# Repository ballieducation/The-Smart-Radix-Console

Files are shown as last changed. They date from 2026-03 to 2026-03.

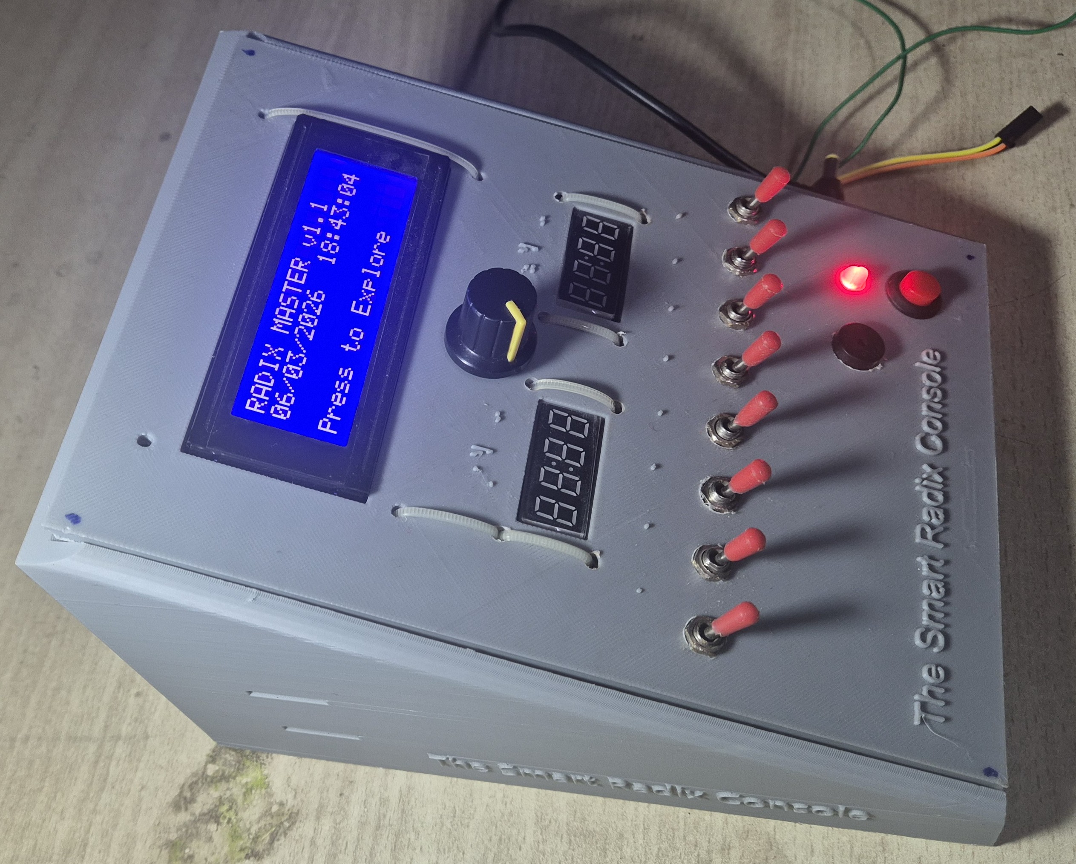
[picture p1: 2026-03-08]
Cover_Image.jpg

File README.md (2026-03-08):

Radix Master v1.1 — Open Source STM32 STEM Learning Console | 12 Games | Binary · DNA · Chemistry
Hands-on educational hardware console teaching Digital Logic, Molecular Biology and Chemistry through interactive switch-based gameplay

## Project Overview

Radix Master v1.1 is a self-contained, hardware-based educational system powered by the STM32 Blue Pill microcontroller. It is designed to bridge the gap between abstract academic theory and genuine conceptual understanding by converting curriculum topics into 
timed, tactile problem-solving challenges.
Students interact with an 8-bit DIP switch array, a rotary encoder, a 20×4 LCD, and dual 7-segment displays — moving learning away from passive screen interaction toward deliberate, physical engagement. The system is fully open-source and customizable for classroom deployment.

━━━━━━━━━━━━━━━━━
## Educational Objectives
━━━━━━━━━━━━━━━━━

This console directly supports learning outcomes in:

COMPUTER SCIENCE
- Binary and hexadecimal number representation
- Bitwise operations: AND, OR, XOR, NAND, NOR, XNOR, NOT
- Base conversion across decimal, binary, and hexadecimal
- Binary arithmetic: addition, subtraction, 
  multiplication, division

MATHEMATICS
- Prime number theory and identification
- Pattern recognition under time pressure

COMMUNICATION TECHNOLOGY  
- Morse code signal encoding and timing

CHEMISTRY & PHYSICS
- Electron shell configuration
- Valence electron identification across 118 elements
- Periodic table navigation

MOLECULAR BIOLOGY
- RNA codon translation using Base-4 encoding
- Gene regulation via bitmask logic
- ABO blood group antigen compatibility

━━━━━━━━━━━━━━━━━
## Hardware Components
━━━━━━━━━━━━━━━━━

Component              | Role
-----------------------|---------------------------
STM32F103C8T6          | Main microcontroller
20×4 I2C LCD (0x27)    | Game display
8-Position DIP Switch  | Student input interface
TM1637 (×2)            | Score + countdown timer
Rotary Encoder         | Menu navigation
Active Buzzer          | Audio feedback
STM32 RTC              | Real-time clock on dashboard

━━━━━━━━━━━━━━━━━
## Pin Mapping
━━━━━━━━━━━━━━━━━

Switch S0–S7    → PA0–PA7   (Digital Input, Pull-up)
Encoder CLK     → PB13      (Interrupt)
Encoder DT      → PB12      (Input)
Encoder SW      → PB14      (Input, Pull-up)
Score TM1637    → PB10/PB11 (CLK/DIO)
Timer TM1637    → PB0/PB1   (CLK/DIO)
I2C LCD         → PB6/PB7   (SCL/SDA)
Buzzer          → PA15      (Digital Output)

━━━━━━━━━━━━━━━━━
## System Architecture
━━━━━━━━━━━━━━━━━

The firmware uses a UIState enum to manage 5 system 
states cleanly:

  STATE_DASHBOARD    — Live RTC clock display
  STATE_MENU         — Scrollable game selector
  STATE_GAME_RUNNING — Active game dispatcher
  STATE_RTC_SETUP    — Field-editable clock setup
  STATE_SELF_TEST    — Hardware diagnostic mode

Each game is assigned a unique activeGame ID and dispatched through a central loop() switch, keeping game logic fully modular and independently expandable.

━━━━━━━━━━━━━━━━━
## The "Ready Gate" Mechanic
━━━━━━━━━━━━━━━━━

Before timed games begin, the system requires the student to reset all 8 switches to the OFF (0) position. 
This physical zeroing serves two purposes:

1. Ensures a fair, clean starting state for every round
2. Acts as a deliberate mental reset — priming the 
   student before the timer begins

━━━━━━━━━━━━━━━━━
## Libraries Required
━━━━━━━━━━━━━━━━━

- Wire.h
- LiquidCrystal_I2C.h
- STM32RTC.h
- TM1637Display.h

━━━━━━━━━━━━━━━━━
## Classroom Deployment Notes
━━━━━━━━━━━━━━━━━

- All string literals use the F() macro to preserve RAM for game variables
- Games are fully independent — teachers can disable specific modules by commenting out menu entries
- Self Test mode allows hardware verification before class sessions
- RTC Setup mode enables accurate date/time stamping without a PC connection

> A hardware-based educational console that teaches Binary Logic, 
> Molecular Biology, Chemistry and Mathematics through 
> real-time, tactile switch-based gameplay.

---

## 📚 Subjects Covered
- 💻 Computer Science — Binary, Hex, Bitwise Logic
- 🧮 Mathematics — Prime Numbers, Binary Arithmetic  
- 📡 Communication — Morse Code
- ⚗️ Chemistry — Electron Shells, Periodic Table
- 🧬 Biology — Codon Translation, Gene Expression, Blood Match

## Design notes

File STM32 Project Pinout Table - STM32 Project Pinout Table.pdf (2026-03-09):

Connection Table (The Smart Radix Console)
S.NO | Component | Component Pin | STM32 Pin | Notes
1 | SPDT Toggle Switch S0 | COM Pin | PA0 | Digital Input Pull-up
2 | SPDT Toggle Switch S1 | COM Pin | PA1 | Digital Input Pull-up
3 | SPDT Toggle Switch S2 | COM Pin | PA2 | Digital Input Pull-up
4 | SPDT Toggle Switch S3 | COM Pin | PA3 | Digital Input Pull-up
5 | SPDT Toggle Switch S4 | COM Pin | PA4 | Digital Input Pull-up
6 | SPDT Toggle Switch S5 | COM Pin | PA5 | Digital Input Pull-up
7 | SPDT Toggle Switch S6 | COM Pin | PA6 | Digital Input Pull-up
8 | SPDT Toggle Switch S7 | COM Pin | PA7 | Digital Input Pull-up
9 | SPDT Toggle Switch S0 | NC Pin | GND | Normally Close to GND
10 | SPDT Toggle Switch S1 | NC Pin | GND | Normally Close to GND
11 | SPDT Toggle Switch S2 | NC Pin | GND | Normally Close to GND
12 | SPDT Toggle Switch S3 | NC Pin | GND | Normally Close to GND
13 | SPDT Toggle Switch S4 | NC Pin | GND | Normally Close to GND
14 | SPDT Toggle Switch S5 | NC Pin | GND | Normally Close to GND
15 | SPDT Toggle Switch S6 | NC Pin | GND | Normally Close to GND
16 | SPDT Toggle Switch S7 | NC Pin | GND | Normally Close to GND
17 | SPDT Toggle Switch S0 | NO Pin | 5V | Normally Open to VCC
18 | SPDT Toggle Switch S1 | NO Pin | 5V | Normally Open to VCC
19 | SPDT Toggle Switch S2 | NO Pin | 5V | Normally Open to VCC
20 | SPDT Toggle Switch S3 | NO Pin | 5V | Normally Open to VCC
21 | SPDT Toggle Switch S4 | NO Pin | 5V | Normally Open to VCC
22 | SPDT Toggle Switch S5 | NO Pin | 5V | Normally Open to VCC
23 | SPDT Toggle Switch S6 | NO Pin | 5V | Normally Open to VCC
24 | SPDT Toggle Switch S7 | NO Pin | 5V | Normally Open to VCC
25 | Rotary Encoder EC11 | CLK (A) | PB13 | Interrupt Input
26 | Rotary Encoder EC11 | DT (B) | PB12 | Digital Input
27 | Rotary Encoder EC11 | SW (Button) | PB14 | Digital Input Pull-up
28 | Rotary Encoder EC11 | GND (-) | GND | Common Ground
29 | Rotary Encoder EC11 | GND (-) | GND | Common Ground
30 | TM1637 Score Display | CLK | PB10 | Serial Clock
31 | TM1637 Score Display | DIO | PB11 | Serial Data
32 | TM1637 Score Display | VCC | 5V | 5V Required
33 | TM1637 Score Display | GND | GND | Common Ground
34 | TM1637 Timer Display | CLK | PB0 | Serial Clock
35 | TM1637 Timer Display | DIO | PB1 | Serial Data
36 | TM1637 Timer Display | VCC | 5V | 5V Required
37 | TM1637 Timer Display | GND | GND | Common Ground
38 | 20x4 I2C LCD | SCL | PB6 | I2C Clock
39 | 20x4 I2C LCD | SDA | PB7 | I2C Data
40 | 20x4 I2C LCD | VCC | 5V | 5V Required
41 | 20x4 I2C LCD | GND | GND | Common Ground
42 | Active Buzzer | Positive (+) | PA15 | Digital Output
43 | Active Buzzer | Negative (-) | GND | Common Ground
44 | 32.768kHz Crystal | Pin 1 | PC14 | OSC32_IN
45 | 32.768kHz Crystal | Pin 2 | PC15 | OSC32_OUT
46 | 22pF Capacitor C1 | Pin 1 | PC14 | Crystal Load Capacitor
47 | 22pF Capacitor C1 | Pin 2 | GND | Crystal Load Capacitor
48 | 22pF Capacitor C2 | Pin 1 | PC15 | Crystal Load Capacitor
49 | 22pF Capacitor C2 | Pin 2 | GND | Crystal Load Capacitor
50 | CR2032 Battery | Positive (+) | VBAT | Via 1N5819 Diode
51 | CR2032 Battery | Negative (-) | GND | Common Ground
52 | 1N5819 Diode | Anode | CR2032 (+) | Overvoltage Protection
53 | 1N5819 Diode | Cathode | VBAT | Stripe Side Faces VBAT
54 | 100nF Capacitor | Pin 1 | VBAT | VBAT Noise Filter
55 | 100nF Capacitor | Pin 2 | GND | Decoupling Capacitor

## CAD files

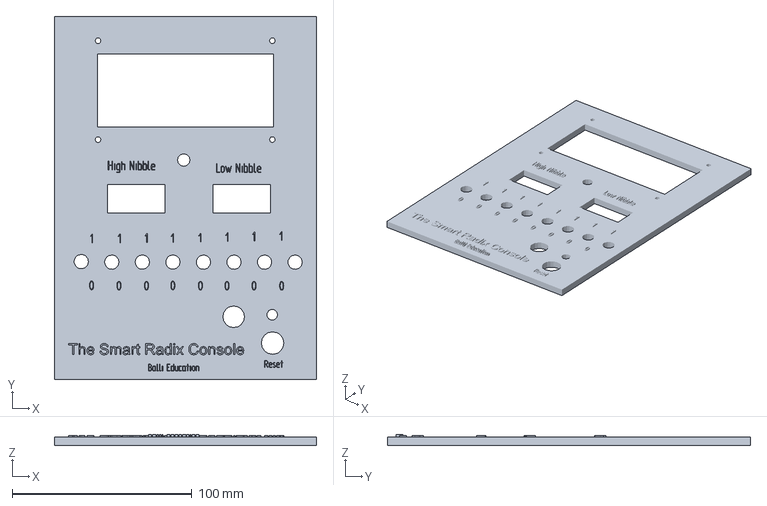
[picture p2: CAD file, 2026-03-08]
Cover_Number_system.3mf
146.0 x 202.0 x 5.90 mm

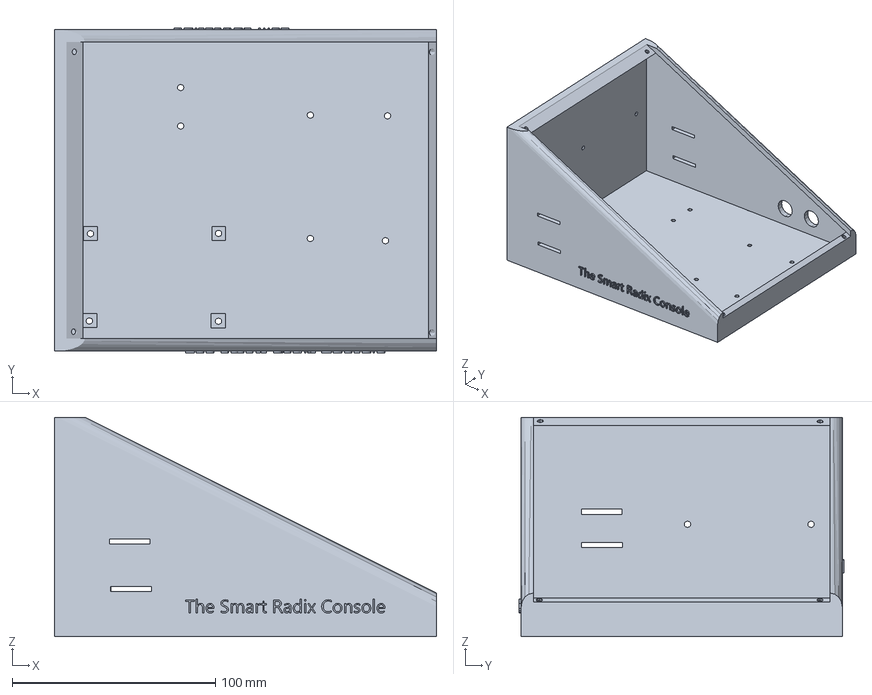
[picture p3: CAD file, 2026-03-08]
Number System Lab Box.3mf
188.0 x 159.7 x 108.0 mm

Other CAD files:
Cover_Number_system.stl
Number System Lab Box.stl

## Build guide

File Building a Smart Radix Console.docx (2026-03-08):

Radix Master v1.1 — STM32 STEM Educational Gaming Console A hardware-based learning system featuring 12 interactive STEM games built on STM32 Blue Pill

Industrial STM32 Project: The Educational Gamified Logic Console

lood Match | Determining safe blood transfusions based on antigens.
System | Self-Test | Hardware diagnostic for switches, encoder, and buzzer.
| RTC Setup | Manual adjustment of the Real-Time Clock.
| Return | Exit to Dashboard.

4. Components & Quantity

Component | Quantity | Purpose
STM32F103C8T6 (Blue Pill) | 1 | Main System Controller (72MHz ARM Cortex-M3).
20x4 I2C LCD | 1 | Main UI for labels, scrolling text, and feedback.
TM1637 4-Digit Display | 2 | High-visibility Score and Timer displays.
EC11 Rotary Encoder | 1 | Menu navigation and value adjustment.
8-Way DIP Switch Array | 1 | 8-bit binary and logic input.
Active/Passive Buzzer | 1 | Auditory feedback for success/error.
32.768kHz Crystal | 1 | LSE Clock source for high-precision RTC.

STM32 Pin Mapping Table

This table shows exactly where every wire from your components must land on the STM32 Blue Pill.

Component | Pin Label | STM32 Pin | Logic Type
8-Bit Switch S0 | Input 0 | PA0 | Digital Input (Pull-up)
8-Bit Switch S1 | Input 1 | PA1 | Digital Input (Pull-up)
8-Bit Switch S2 | Input 2 | PA2 | Digital Input (Pull-up)
8-Bit Switch S3 | Input 3 | PA3 | Digital Input (Pull-up)
8-Bit Switch S4 | Input 4 | PA4 | Digital Input (Pull-up)
8-Bit Switch S5 | Input 5 | PA5 | Digital Input (Pull-up)
8-Bit Switch S6 | Input 6 | PA6 | Digital Input (Pull-up)
8-Bit Switch S7 | Input 7 | PA7 | Digital Input (Pull-up)
Rotary Encoder | A (CLK) | PB13 | Interrupt / Input
Rotary Encoder | B (DT) | PB12 | Input
Rotary Encoder | SW (Button) | PB14 | Input (Pull-up)
Score TM1637 | CLK | PB10 | Serial Clock
Score TM1637 | DIO | PB11 | Serial Data
Timer TM1637 | CLK | PB0 | Serial Clock
Timer TM1637 | DIO | PB1 | Serial Data
I2C 20x4 LCD | SCL | PB6 | I2C Clock
I2C 20x4 LCD | SDA | PB7 | I2C Data
Buzzer (Active) | Positive (+) | PA15 | Digital Output

Project Description

Radix Master v1.1 is a hardware-based educational gaming system powered by an STM32 microcontroller. It integrates binary logic, mathematics, electronics, chemistry, and biology into a single interactive console.

Students use:

- 8-bit physical switches
- Rotary encoder navigation
- Dual 7-segment displays
- 20x4 LCD screen
- Real-time timer (RTC)

Each game challenges students to solve problems using binary logic and switch patterns, reinforcing computational thinking and scientific reasoning.

The system contains 12+ educational games including:

- Binary Blitz
- Radix Roulette
- Bitwise Logic
- Prime Hunter
- Morse Trainer
- Electron Shells
- Periodic Table
- Codon Explorer
- Gene Expression
- Blood Match

It is fully open-source and customizable.

1. Digital Logic & Number Systems

Module | What it is | How to use it | Concepts Learned | Gamification Used
Binary Blitz | A rapid-fire decimal to binary translator. | Convert the decimal "Target" on the LCD into 8-bit switch positions. | Binary weights (2^n), Bit-positioning. | Time Pressure: 30s limit forces "Instant Recall" instead of manual counting.
Radix Roulette | A multi-base conversion emulator. | Convert targets appearing in Hex (0x), Octal (0), or Dec into Binary. | Cross-radix translation, Hexadecimal notation. | Variable Reward: Higher points for complex Hex-to-Bin conversions.
Bitwise Logic | A physical Truth Table simulator. | Given two 8-bit values and an operator (XOR, NAND, etc.), set the switches to the result. | Logic Gates (AND/OR/XOR), Masking, Boolean Algebra. | Visual Feedback: LCD shows "MATCH!" only when the logic gate result is perfect.

Physical & Life Sciences (The Emulators)

Module | What it is | How to use it | Concepts Learned | Gamification Used
Electron Shells | An atomic stability simulator. | Set the switches to match the required valence electrons for a specific element. | The Octet Rule (2, 8, 8), Atomic Numbers (Z), Valency. | Status Simulation: Shows "IONIC STATE" vs. "STABLE ATOM" based on input.
Codon Explorer | A Base-4 DNA-to-Protein translator. | Map 2-bit pairs (S0-S1, etc.) to A, C, G, U bases to build an Amino Acid. | Genetic Code, mRNA triplet codons, Base-4 logic. | High Stakes: 150-point reward for correctly "Synthesisng" a complex Protein.
Gene Expression | A phenotype activation emulator. | Match a 8-bit "Regulatory Mask" to express a trait like "Blue Eyes" or "Immunity." | Transcription Factors, Bit masking, Gene Regulation. | Scrolling HUD: Uses a scrolling "Phenotype" display to mimic a sequencing lab.
Blood Match | An Immuno-Logic Truth Table. | Use S0, S1, S2 as A, B, Rh antigens to match a patient’s blood type. | Immunology, Antigens/Antibodies, Biological compatibility. | Risk Assessment: Displays "!!DANGER!!" and triggers the buzzer on a mismatch.

3. Communications & Math

Module | What it is | How to use it | Concepts Learned | Gamification Used
Morse Trainer | A telegraphy hardware emulator. | Use Switch 0 (S0) as a physical key to input the Morse code for a target letter. | International Morse Code, Timing (Dits vs. Dahs). | Live Progress Bar: LCD shows a real-time charging bar to distinguish short vs. long presses.
Prime Hunter | A numerical classification game. | Look at 8 random numbers and toggle the switches only for the Prime ones. | Prime vs. Composite numbers, Factorization. | Reset Gate: Forces the user to reset all switches to "0" before the next round to ensure focus.

🕹️ User Interaction & Gameplay Flow

The Radix Console is designed for high-tactile engagement, moving away from a mouse and keyboard to a dedicated industrial interface. Here is the step-by-step player journey:

1. System Boot & Navigation

Upon power-up, the player is greeted by the Dashboard, displaying the real-time clock and date. To enter the learning environment, the player clicks the Rotary Encoder. By rotating the dial, they scroll through the 12+ educational emulators on the 20x4 LCD. A second click selects the desired module.

2. The "Ready Gate" Mechanism

To ensure fairness and "Reset Thinking," most games (like Prime Hunter or Bitwise Logic) will not start until the player toggles all 8 hardware switches to the '0' (OFF) position. This physical "Zeroing" acts as a mental reset before the timer begins.

3. Real-Time Problem Solving

Once the game starts:

- The Challenge: The top row of the LCD displays a target (e.g., a Decimal number, a Chemical element, or a DNA Codon).
- The Input: The player manipulates the 8-bit switch array. In Binary Blitz, they map values to binary weights (2^n); in Codon Explorer, they treat pairs of switches as A, C, G, or U bases.
- The Feedback: The left TM1637 display shows the live score, while the right display counts down the remaining seconds.

4. Success & Evolution

When the player matches the target logic, the Active Buzzer provides an immediate "Success Beep," and the score increments. In the Gene Expression emulator, the LCD might scroll a new "Phenotype" to express, forcing the player to quickly recalculate their bitmask. If the timer hits zero, the final score is flashed across the LCD, and the player is returned to the menu to try a different challenge.

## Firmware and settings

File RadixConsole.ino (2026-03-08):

#include <Wire.h>
#include <LiquidCrystal_I2C.h>
#include <STM32RTC.h>
#include <TM1637Display.h>

// ================= PINS =================
#define CLK_LEFT   PB10
#define DIO_LEFT   PB11
#define CLK_RIGHT  PB0
#define DIO_RIGHT  PB1
#define ENC_A      PB13
#define ENC_B      PB12
#define ENC_SW     PB14
#define BUZZER     PA15

// ================= BINARY BLITZ VARS =================
int blitzTarget = 0;
int blitzScore = 0;
unsigned long blitzStartTime = 0;
const int blitzTimeLimit = 30; 

const int switchPins[8] = {PA0, PA1, PA2, PA3, PA4, PA5, PA6, PA7}; 


// ================= RADIX ROULETTE VARS =================
int rouletteTarget = 0;
int rouletteScore = 0;
uint8_t currentBase = 10; // 10 = Dec, 16 = Hex, 2 = Binary
unsigned long rouletteStartTime = 0;
const int rouletteTimeLimit = 20; // Faster than Blitz!


// ================= GLOBAL GAME VARIABLES =================
int activeGame = -1;       // Tracks which game is running
int scoreVal = 0;          // Shared score variable
int targetVal = 0;         // Shared target variable
unsigned long gameStartTime = 0; 

// --- BIT RUNNER SPECIFIC ---
//uint8_t runnerPos = 0;     // Current position of the bit
//int moveDelay = 800;       // Speed of movement
//unsigned
 //long lastMove = 0;
 uint8_t runnerPos = 0;      // Current position (0 to 7)
unsigned long lastMove = 0; // Timing tracker
int moveDelay = 800;        // Start speed (ms)


// --- FULL BINARY ARITHMETIC ---
int numA = 0;
int numB = 0;
char currentOp = '+';
int arithmeticTarget = 0;
uint8_t opType = 0; // 0=Add, 1=Sub, 2=Mul, 3=Div


// --- PRIME HUNTER V2 VARS ---
int hunterNumbers[8];
byte primeMask = 0;       // Each bit represents if the corresponding number is prime
bool rowCleared = false;



// Bitwise Game Variables
byte valA = 0;
byte valB = 0;
byte bitwiseTarget = 0;
char currentBitOpName[4] = "   ";

void lcdPrintBinary(byte val); // Just the name, no brackets/logic





// ================= OBJECTS =================
TM1637Display tmScore(CLK_LEFT, DIO_LEFT);
TM1637Display tmTimer(CLK_RIGHT, DIO_RIGHT);
LiquidCrystal_I2C lcd(0x27, 20, 4);
STM32RTC& rtc = STM32RTC::getInstance();

// ================= MENU DEFINITIONS =================
// Use const char* const to ensure these stay in Flash
const char* const mainMenu[] = {
  "Binary Blitz", "Radix Roulette", "Bit Runner", "Binary Arithmetic",
  "Bitwise Logic", "Prime Hunter", "Morse Trainer", "Electron Shells",
  "Periodic Table", "Codon Explorer", "Gene Expression", "Blood Match",
  "Self Test", "RTC Setup", "Return"
};
#define MENU_COUNT 15

enum UIState { STATE_DASHBOARD, STATE_MENU, STATE_RTC_SETUP, STATE_SELF_TEST, STATE_GAME_RUNNING };
UIState uiState = STATE_DASHBOARD;

// ================= GLOBAL VARIABLES =================
int menuIndex = 0;
int menuTopIndex = 0;
bool lastEncA;
unsigned long buttonPressStart = 0;
bool buttonHeld = false;

int selfCounter = 0;
bool selfLastA;
int editDay, editMonth, editYear, editHour, editMinute, editField;


// Morse Trainer Variables
char morseTarget;
String userMorseBuffer = "";
unsigned long pressStart = 0;
bool isKeyActive = false;

// Morse Reference Table
const char* morseTable[] = {
  ".-", "-...", "-.-.", "-..", ".", "..-.", "--.", "....", "..", ".---", 
  "-.-", ".-..", "--", "-.", "---", ".--.", "--.-", ".-.", "...", "-", 
  "..-", "...-", ".--", "-..-", "-.--", "--.."
};

void nextMorseLetter() {
  morseTarget = 'A' + random(0, 26);
  userMorseBuffer = "";
}


// --- ELECTRON SHELLS & PERIODIC TABLE VARS ---
int targetAtomicNum = 0;
String elementName = "";
int requiredValence = 0;
int currentZ = 1;

// Element Names for Case 7 (L-Shell focus)
const char* const shellElements[] = {
  "Lithium", "Beryllium", "Boron", "Carbon", 
  "Nitrogen", "Oxygen", "Fluorine", "Neon"
};

// Valence electrons for all 118 elements (for Case 8)
const uint8_t valenceTable[118] = {
  1, 2,                                                             // H, He
  1, 2, 3, 4, 5, 6, 7, 8,                                           // Li to Ne
  1, 2, 3, 4, 5, 6, 7, 8,                                           // Na to Ar
  1, 2, 2, 2, 2, 2, 2, 2, 2, 2, 3, 4, 5, 6, 7, 8,                   // K to Kr
  1, 2, 2, 2, 2, 2, 2, 2, 2, 2, 3, 4, 5, 6, 7, 8,                   // Rb to Xe
  1, 2, 2, 2, 2, 2, 2, 2, 2, 2, 2, 2, 2, 2, 2, 2, 2, 2, 2, 2, 2, 2, 2, 2, 2, 3, 4, 5, 6, 7, 8,
  1, 2, 2, 2, 2, 2, 2, 2, 2, 2, 2, 2, 2, 2, 2, 2, 2, 2, 2, 2, 2, 2, 2, 2, 2, 3, 4, 5, 6, 7, 8 
};





// --- Global Declarations ---
// --- CODON EXPLORER GLOBALS ---
String targetAmino = "";
String targetCodon = "";

struct CodonData {
  char amino[12];
  char codon[4];
};

// Gamification: Focus on the "Vital" codons
const CodonData geneticLibrary[] = {
  {"START/MET", "AUG"}, {"STOP", "UAA"}, {"GLYCINE", "GGG"},
  {"VALINE", "GUU"}, {"ALANINE", "GCU"}, {"LYSINE", "AAA"},
  {"STOP/AMB", "UAG"}, {"CYSTEINE", "UGU"}
};



// --- GENE EXPRESSION GLOBALS ---
String targetPhenotype = "";
byte regulatoryMask = 0;

struct GeneData {
  char phenotype[16];
  byte mask; // The required switch pattern
};

const GeneData geneLibrary[] = {
  {"Blue Eyes",    0b10101010},
  {"Build Muscle", 0b11110000},
  {"Fast Metabolism", 0b00001111},
  {"Glow in Dark", 0b10011001},
  {"High Immunity", 0b01010101},
  {"Brain Power",  0b11001100}
};



// --- BLOOD MATCH GLOBALS ---
String patientType = "";
byte donorTargetMask = 0;

struct BloodData {
  char typeName[5];
  byte mask; // S0=A, S1=B, S2=Rh
};

const BloodData bloodLibrary[] = {
  {"A+",  0b101}, {"A-",  0b001},
  {"B+",  0b110}, {"B-",  0b010},
  {"AB+", 0b111}, {"AB-", 0b011},
  {"O+",  0b100}, {"O-",  0b000}
};










void nextElectronProblem() {
  int idx = random(0, 8); 
  elementName = shellElements[idx];
  requiredValence = idx + 1; 
  targetAtomicNum = idx + 3; // Li starts at Z=3
}

void nextElementProblem() {
  currentZ = random(1, 119);
}


void showElectronFinalScore() {
  lcd.clear();
  digitalWrite(BUZZER, HIGH); delay(500); digitalWrite(BUZZER, LOW);
  lcd.setCursor(2, 1); lcd.print(F("SHELLS FINISHED!"));
  lcd.setCursor(4, 2); lcd.print(F("SCORE: ")); lcd.print(scoreVal);
  tmScore.showNumberDec(scoreVal);
  delay(5000); 
  uiState = STATE_MENU; showMenu();
}

void showPeriodicFinalScore() {
  lcd.clear();
  digitalWrite(BUZZER, HIGH); delay(500); digitalWrite(BUZZER, LOW);
  lcd.setCursor(1, 1); lcd.print(F("PERIODIC OVER!"));
  lcd.setCursor(4, 2); lcd.print(F("SCORE: ")); lcd.print(scoreVal);
  tmScore.showNumberDec(scoreVal);
  delay(5000);
  uiState = STATE_MENU; showMenu();
}











// ================= HELPERS =================
void print2digit(int val) { 
  if (val < 10) lcd.print('0'); 
  lcd.print(val); 
}

// ================= DISPATCHER =================
void executeMenuAction(int index) {
  lcd.clear();
  switch(index) {
    case 0:  startBinaryBlitz(); break;
    case 1: startRadixRoulette(); break; // <-- NEW
    case 2: // Bit Runner
      uiState = STATE_GAME_RUNNING;
      activeGame = 2;
      scoreVal = 0;
      runnerPos = 0;
      moveDelay = 800; // Reset to slow speed
      gameStartTime = millis();
      lcd.clear();
      lcd.print(F("--- BIT RUNNER ---"));
      break;

   case 3: // Binary Arithmetic
  uiState = STATE_GAME_RUNNING;
  activeGame = 3;
  scoreVal = 0;
  gameStartTime = millis();
  nextBinaryArithmeticProblem(); // <--- CRITICAL: Generates first A and B
  lcd.clear();
  break;

case 4: // Bitwise Logic Entry
  lcd.clear();
  lcd.setCursor(0, 0);
  lcd.print(F("---BITWISE LOGIC---"));
  lcd.setCursor(0, 2);
  lcd.print(F("RESET ALL SWITCHES"));
  
  // Wait until all switches are toggled to 0
  while(readSwitches() != 0) {
    delay(50);
  }

  scoreVal = 0;
  nextBitwiseProblem();
  gameStartTime = millis(); // 60s Timer starts only after reset
  uiState = STATE_GAME_RUNNING;
  activeGame = 4; 
  lcd.clear();
  break;


case 5: // Prime Hunter Entry
  lcd.clear();
  lcd.setCursor(0, 0);
  lcd.print(F("---PRIME HUNTER---"));
  lcd.setCursor(0, 2);
  lcd.print(F("RESET ALL SWITCHES"));
  lcd.setCursor(0, 3);
  lcd.print(F("TO START CLOCK..."));

  // The "Ready" Gate
  while(readSwitches() != 0) {
    delay(50); 
  }

  // Initialize after reset
  scoreVal = 0;
  nextPrimeRow();
  gameStartTime = millis(); // Timer starts NOW
  uiState = STATE_GAME_RUNNING;
  activeGame = 5;
  lcd.clear();
  break;

case 6: // Morse Trainer Entry
  lcd.clear();
  lcd.print(F("MORSE TRAINER"));
  lcd.setCursor(0, 2);
  lcd.print(F("RESET ALL SWITCHES"));
  
  while(readSwitches() != 0) { delay(10); } // Reset Gate

  scoreVal = 0;
  nextMorseLetter();
  gameStartTime = millis();
  activeGame = 6;
  uiState = STATE_GAME_RUNNING;
  lcd.clear();
  break;



case 7: // Electron Shells Menu Selection
  lcd.clear();
  lcd.setCursor(0, 0);
  lcd.print(F("---ELECTRON SHELL---"));
  lcd.setCursor(0, 2);
  lcd.print(F("RESET ALL SWITCHES"));
  
  // Wait for safety reset
  while(readSwitches() != 0) { delay(10); }

  scoreVal = 0;
  nextElectronProblem();     // Pick first element
  gameStartTime = millis();  // Start timer
  activeGame = 7;            // Set ID to 7
  uiState = STATE_GAME_RUNNING;
  lcd.clear();
  break;









case 8: // Periodic Table Game Entry
  lcd.clear();
  lcd.print(F("PERIODIC TABLE"));
  lcd.setCursor(0, 2);
  lcd.print(F("RESET ALL SWITCHES"));
  
  while(readSwitches() != 0) { delay(10); } // Wait for 00000000

  scoreVal = 0;
  currentZ = random(1, 119); // Pick random Z from 1 to 118
  gameStartTime = millis();
  activeGame = 8;            // Assign unique ID
  uiState = STATE_GAME_RUNNING;
  lcd.clear();
  break;


case 9: // Codon Explorer
  lcd.clear();
  lcd.print(F("CODON EXPLORER"));
  while(readSwitches() != 0) { delay(10); } // Gamification: Clear the deck
  scoreVal = 0;
  nextCodonProblem();
  gameStartTime = millis();
  activeGame = 9;
  uiState = STATE_GAME_RUNNING;
  lcd.clear();
  break;


case 10: // Gene Expression Entry
  lcd.clear();
  lcd.print(F("EXPRESS:"));  // Static Label Row 0
  lcd.setCursor(0, 1);
  lcd.print(F(" GENOME:"));   // Static Label Row 1
  lcd.setCursor(0, 3);
  lcd.print(F("SEEKING HOMEOSTASIS")); // Static Label Row 3
  
  scoreVal = 0;
  nextGeneProblem();
  gameStartTime = millis();
  activeGame = 10;
  uiState = STATE_GAME_RUNNING;
  break;



case 11: // Blood Match Entry
  lcd.clear();
  lcd.setCursor(0, 0); lcd.print(F("PATIENT : "));
  lcd.setCursor(0, 1); lcd.print(F("DONOR   : "));
  lcd.setCursor(0, 3); lcd.print(F("S0=A S1=B S2=Rh")); // Tutorial Row
  
  scoreVal = 0;
  nextBloodProblem();
  gameStartTime = millis();
  activeGame = 11;
  uiState = STATE_GAME_RUNNING;
  break;





    case 12: startSelfTest();    break;
    case 13: uiState = STATE_RTC_SETUP; enterRTCSetup(); break;
    case 14: uiState = STATE_DASHBOARD; showDashboard(); break;
    default:
      lcd.setCursor(0,1); lcd.print(F("Starting..."));
      lcd.setCursor(0,2); lcd.print(mainMenu[index]);
      delay(1000);
      break;
  }
}

// ================= GAME LOGIC =================
void runBinaryBlitz() {
  int remaining = blitzTimeLimit - ((millis() - blitzStartTime) / 1000);
  if (remaining <= 0) {
    digitalWrite(BUZZER, HIGH); delay(500); digitalWrite(BUZZER, LOW);
    lcd.clear();
    lcd.setCursor(5, 1); lcd.print(F("GAME OVER!"));
    lcd.setCursor(4, 2); lcd.print(F("Score: ")); lcd.print(blitzScore);
    delay(3000);
    uiState = STATE_MENU; showMenu();
    return;
  }

  tmTimer.showNumberDec(remaining);
  tmScore.showNumberDec(blitzScore);

  byte playerInput = 0;
  for (int i = 0; i < 8; i++) if (digitalRead(switchPins[i]) == LOW) playerInput |= (1 << i);

  lcd.setCursor(0, 1); lcd.print(F("TARGET: ")); lcd.print(blitzTarget); lcd.print(F("    "));
  lcd.setCursor(0, 2); lcd.print(F("YOURS : ")); lcd.print(playerInput); lcd.print(F("    "));

  if (playerInput == blitzTarget) {
    digitalWrite(BUZZER, HIGH); delay(100); digitalWrite(BUZZER, LOW);
    blitzScore += 10;
    blitzTarget = random(1, 255);
    blitzStartTime = millis();
    lcd.setCursor(0, 3); lcd.print(F("CORRECT! NEXT...   "));
    delay(500);
    lcd.setCursor(0, 3); lcd.print(F("                   "));
  }
}

void startBinaryBlitz() {
  uiState = STATE_GAME_RUNNING;
  blitzScore = 0;
  blitzTarget = random(1, 255);
  blitzStartTime = millis();
  lcd.clear();
  lcd.print(F("--- BINARY BLITZ ---"));
  tmScore.clear();
}

// ================= RADIX ROULETTE  =================
void startRadixRoulette() {
  uiState = STATE_GAME_RUNNING;
  rouletteScore = 0;
  rouletteTarget = random(1, 255);
  currentBase = 10; // Start with Decimal
  rouletteStartTime = millis();
  
  lcd.clear();
  lcd.print(F("--- RADIX ROULETTE ---"));
  tmScore.clear();
}

void runRadixRoulette() {
  int remaining = rouletteTimeLimit - ((millis() - rouletteStartTime) / 1000);

  if (remaining <= 0) {
    digitalWrite(BUZZER, HIGH); delay(500); digitalWrite(BUZZER, LOW);
    lcd.clear();
    lcd.setCursor(4, 1); lcd.print(F("ROULETTE OVER"));
    lcd.setCursor(4, 2); lcd.print(F("Score: ")); lcd.print(rouletteScore);
    delay(3000);
    uiState = STATE_MENU; showMenu();
    return;
  }

  tmTimer.showNumberDec(remaining);
  tmScore.showNumberDec(rouletteScore);

  // Read switches
  byte playerInput = 0;
  for (int i = 0; i < 8; i++) if (digitalRead(switchPins[i]) == LOW) playerInput |= (1 << i);

  // Display Target based on current base
  lcd.setCursor(0, 1);
  if (currentBase == 10) {
    lcd.print(F("DEC TARGET: ")); lcd.print(rouletteTarget); 
  } else if (currentBase == 16) {
    lcd.print(F("HEX TARGET: 0x")); lcd.print(rouletteTarget, HEX);
  } else {
    lcd.print(F("BIN TARGET: ")); lcd.print(rouletteTarget, BIN);
  }
  lcd.print(F("    ")); // Clear trailing characters

  lcd.setCursor(0, 2);
  lcd.print(F("YOUR INPUT: ")); lcd.print(playerInput); lcd.print(F("    "));

  // Check Success
  if (playerInput == rouletteTarget) {
    digitalWrite(BUZZER, HIGH); delay(80); digitalWrite(BUZZER, LOW);
    rouletteScore += 15; // Higher reward for Radix
    rouletteTarget = random(1, 255);
    
    // Pick a new random base for the next round
    int r = random(0, 3);
    if (r == 0) currentBase = 10;
    else if (r == 1) currentBase = 16;
    else currentBase = 2;

    rouletteStartTime = millis(); // Reset timer
    lcd.setCursor(0, 3); lcd.print(F("GREAT! CHANGING... "));
    delay(600);
    lcd.setCursor(0, 3); lcd.print(F("                   "));
  }
}

// --- BIT RUNNER VARIABLES ---



byte readSwitches() {
  byte val = 0;
  for (int i = 0; i < 8; i++) {
    if (digitalRead(switchPins[i]) == LOW) val |= (1 << i);
  }
  return val;
}
void runBitRunner() {
  // 1. Timer Logic
  int remaining = 30 - ((millis() - gameStartTime) / 1000);
  if (remaining <= 0) {
    digitalWrite(BUZZER, HIGH); delay(500); digitalWrite(BUZZER, LOW);
    lcd.clear(); lcd.print(F("Runner Finished!"));
    lcd.setCursor(0, 2); lcd.print(F("Final Score: ")); lcd.print(scoreVal);
    delay(3000); uiState = STATE_MENU; showMenu(); return;
  }

  // 2. Display Updates
  tmTimer.showNumberDec(remaining);
  tmScore.showNumberDec(scoreVal);

  // 3. The Movement Logic
  if (millis() - lastMove > moveDelay) {
    lastMove = millis();
    runnerPos = (runnerPos + 1) % 8; // Move to next bit
    targetVal = (1 << runnerPos);    // Update the target bit value
    
    // Increase difficulty: speed up slightly every move
    if (moveDelay > 200) moveDelay -= 5; 
  }

  // 4. LCD Feedback
  lcd.setCursor(0, 1);
  lcd.print(F("CATCH BIT: "));
  // Show the bit position visually
  for(int i=7; i>=0; i--) {
    lcd.print(i == runnerPos ? '1' : '0');
  }

  lcd.setCursor(0, 2);
  byte input = readSwitches();
  lcd.print(F("YOUR POS:  "));
  for(int i=7; i>=0; i--) {
    lcd.print(bitRead(input, i) ? '1' : '0');
  }

  // 5. Scoring
  if (input == targetVal) {
    // We don't use a long delay here so the bit keeps moving
    scoreVal += 1; // Constant scoring for staying on the bit
    digitalWrite(BUZZER, (millis() % 200 < 50)); // Tiny blip when matched
  } else {
    digitalWrite(BUZZER, LOW);
  }
}


///////////////////////////////////
//////////////////////////////////////
////////////////////////////////////////
void lcdPrintBinary(byte val) {
  for (int i = 7; i >= 0; i--) {
    lcd.print(bitRead(val, i));
  }
}
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
void loop() {
  handleEncoder();
  handleButton();
  switch (uiState) {
    case STATE_DASHBOARD:    updateDashboardTick(); break;
    case STATE_SELF_TEST:    runSelfTest(); break;
    //case STATE_GAME_RUNNING: runBinaryBlitz(); break;
    case STATE_GAME_RUNNING: 
       if (menuIndex == 0) runBinaryBlitz();
       else if (menuIndex == 1) runRadixRoulette();
       else if (activeGame == 2) runBitRunner(); // <--- Add this
       else if (activeGame == 3) runBinaryArithmetic(); // <--- CALL HERE 
       else if (activeGame == 4) runBitwiseGame();       // <--- ADD THIS CALL FOR CASE 4
       else if (activeGame == 5) runPrimeHunter(); // <--- CALL HERE 
       else if (activeGame == 6) runMorseTrainer(); // <--- CALL HERE 
       else if (activeGame == 7) runElectronShells();
       else if (activeGame == 8) runPeriodicTableGame(); // <--- NEW CALL
       else if (activeGame == 9) runCodonExplorer();
       else if (activeGame == 10) runGeneExpression(); // Logic Gates in Biology
       else if (activeGame == 11) runBloodMatch();  // Logic Gates in Biology
       break;

  }
}

// ================= UI HANDLERS =================
void handleEncoder() {
  bool currentA = digitalRead(ENC_A);
  if (currentA == LOW && lastEncA == HIGH) {
    int dir = (digitalRead(ENC_B) != currentA) ? 1 : -1;
    if (uiState == STATE_MENU) {
      menuIndex = (menuIndex + dir + MENU_COUNT) % MENU_COUNT;
      showMenu();
    } else if (uiState == STATE_RTC_SETUP) adjustRTCField(dir);
  }
  lastEncA = currentA;
}

void handleButton() {
  bool btn = digitalRead(ENC_SW);
  if (btn == LOW && !buttonHeld) { buttonPressStart = millis(); buttonHeld = true; }
  if (btn == HIGH && buttonHeld) {
    unsigned long duration = millis() - buttonPressStart;
    buttonHeld = false;
    if (duration < 600) {
      if (uiState == STATE_DASHBOARD) { uiState = STATE_MENU; showMenu(); } 
      else if (uiState == STATE_MENU) executeMenuAction(menuIndex);
      else if (uiState == STATE_RTC_SETUP) { editField = (editField + 1) % 5; positionCursor(); }
      else if (uiState == STATE_SELF_TEST) { uiState = STATE_MENU; showMenu(); }
    } else {
      if (uiState == STATE_RTC_SETUP) saveRTC();
      else { uiState = STATE_DASHBOARD; showDashboard(); }
    }
  }
}

void showMenu() {
  lcd.clear(); lcd.print(F("--- RADIX MENU ---"));
  if (menuIndex < menuTopIndex) menuTopIndex = menuIndex;
  if (menuIndex > menuTopIndex + 2) menuTopIndex = menuIndex - 2;
  for (int i = 0; i < 3; i++) {
    int itemIdx = menuTopIndex + i;
    if (itemIdx >= MENU_COUNT) break;
    lcd.setCursor(0, i + 1);
    lcd.print(itemIdx == menuIndex ? F("> ") : F("  "));
    lcd.print(mainMenu[itemIdx]);
  }
}

void updateDashboardTick() {
  static unsigned long lastUpdate = 0;
  if (millis() - lastUpdate >= 1000) {
    lastUpdate = millis();
    lcd.setCursor(0,1);
    int y = rtc.getYear();
    if (y < 100) y += 2000;
    print2digit(rtc.getDay()); lcd.print('/');
    print2digit(rtc.getMonth()); lcd.print('/');
    lcd.print(y); lcd.print(F("  "));
    print2digit(rtc.getHours()); lcd.print(':');
    print2digit(rtc.getMinutes()); lcd.print(':');
    print2digit(rtc.getSeconds());
  }
}

void showDashboard() {
  lcd.clear(); lcd.print(F("RADIX MASTER v1.1"));
  lcd.setCursor(0,3); lcd.print(F("Press to Explore"));
}

void startSelfTest() {
  uiState = STATE_SELF_TEST;
  lcd.clear(); lcd.print(F("SELF TEST MODE"));
  selfCounter = 0; tmScore.clear(); tmTimer.clear();
}

void runSelfTest() {
  byte binVal = 0;
  for (int i = 0; i < 8; i++) if (digitalRead(switchPins[i]) == LOW) binVal |= (1 << i);
  bool curA = digitalRead(ENC_A);
  if (curA != selfLastA && curA == LOW) {
    if (digitalRead(ENC_B) != curA) selfCounter++; else selfCounter--;
    digitalWrite(BUZZER, HIGH); delay(10); digitalWrite(BUZZER, LOW);
  }
  selfLastA = curA;
  tmScore.showNumberDec(binVal);
  tmTimer.showNumberDec(selfCounter);
  lcd.setCursor(0,1); lcd.print(F("BIN: "));
  for(int i=7; i>=0; i--) lcd.print(bitRead(binVal, i));
  lcd.setCursor(0,2); lcd.print(F("DEC:")); lcd.print(binVal); 
  lcd.print(F(" HEX:")); lcd.print(binVal, HEX); lcd.print(F("   "));
  lcd.setCursor(0,3);
  if (digitalRead(ENC_SW) == LOW) { lcd.print(F("BTN: PRESSED   ")); digitalWrite(BUZZER, HIGH); } 
  else { lcd.print(F("BTN: OPEN      ")); digitalWrite(BUZZER, LOW); }
}

void enterRTCSetup() {
  editDay = rtc.getDay(); editMonth = rtc.getMonth(); 
  editYear = rtc.getYear() + 2000;
  editHour = rtc.getHours(); editMinute = rtc.getMinutes();
  editField = 0; lcd.cursor(); lcd.blink(); showRTCSetup();
}

void showRTCSetup() {
  lcd.setCursor(0,1); lcd.print(F("D:")); print2digit(editDay);
  lcd.print(F(" M:")); print2digit(editMonth);
  lcd.print(F(" Y:")); lcd.print(editYear);
  lcd.setCursor(0,2); lcd.print(F("Time: ")); print2digit(editHour);
  lcd.print(':'); print2digit(editMinute);
  positionCursor();
}

void adjustRTCField(int delta) {
  if(editField==0) editDay = constrain(editDay+delta,1,31);
  else if(editField==1) editMonth = constrain(editMonth+delta,1,12);
  else if(editField==2) editYear = constrain(editYear+delta,2024,2099);
  else if(editField==3) editHour = constrain(editHour+delta,0,23);
  else if(editField==4) editMinute = constrain(editMinute+delta,0,59);
  showRTCSetup();
}

void positionCursor() {
  if(editField==0) lcd.setCursor(2,1);
  else if(editField==1) lcd.setCursor(7,1);
  else if(editField==2) lcd.setCursor(12,1);
  else if(editField==3) lcd.setCursor(6,2);
  else if(editField==4) lcd.setCursor(9,2);
}

void saveRTC() {
  rtc.setDate(editDay, editMonth, editYear - 2000);
  rtc.setTime(editHour, editMinute, 0);
  lcd.noCursor(); lcd.noBlink();
  uiState = STATE_DASHBOARD; showDashboard();

}
